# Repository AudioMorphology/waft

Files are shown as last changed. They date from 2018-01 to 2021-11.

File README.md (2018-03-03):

# waft
Eurorack Gesture Controller

## Overview

Waft is a LIDAR-based gesture controller in Eurorack format.

It is based around the VL6180x Time Of Flight controller, which measures distances using a low-power Infra-red LASER emitter but, unlike most IR distance measuring devices, which estimate distance based on reflected signals, the VL6180x measures the actual round-trip (Time Of Flight) delay. So, maybe 'gesture' perhaps overstates it slightly - it doesn't recognise gestures such as swipe up, swipe down etc., though it _**does**_ measure distance with mm accuracy over a distance of 20cm or thereabouts.... 

The VL6180X is the latest product based on ST Microelectronics'patented FlightSense™ technology. It uses a SPAD (Single Photon Avalanche Diode) array coupled with a VCSEL (Vertical Cavity Surface-Emitting Laser). The VL6180x also incorporates an Ambient Light Sensor, though we're not making use of that here.

Waft utilises the widely-available Arduino Nano V3 board as its processing core, and an mcp4728 12-Bit I2C quad-channel DAC for the CV Outputs.

Waft generates two CV and two Gate outputs:

* CV1 - 0-8v Range, not quantised
* CV2 - 0-2v Range, quantised to a series of selectable scales
* Gate 1 - On if any object detected
* gate 2 - On triggered by movement only

In addition, a CV Input can be mixed with a variable amount of CV1, thus the Waft controller can be used to modulate a CV input.

The hardware design (Schematics & Gerbers) are released under the Open Source Hardware Association (UID UK000005), and the Software is available under a Creative Commons / MIT license.

All documentation is held in the Wiki

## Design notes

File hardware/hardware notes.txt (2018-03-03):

Miniature 10-Way BCD Switches are available from various places on the web, or RS-Components, part #616-0653

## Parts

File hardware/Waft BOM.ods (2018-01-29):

Waft gesture Controller – Bill of Materials |  |  |  |  | 652-CR0805FX-3301ELF (https://www.mouser.co.uk/ProductDetail/Bourns/CR0805-FX-3301ELF)
Resistors | Value | Size | Mouser Part # | Manufacturer part number
R1 | 3k3 | 0805 | 71-RCS08053K30FKEA (https://www.mouser.co.uk/ProductDetail/Vishay/RCS08053K30FKEA) | CR0805-FX-3301ELF
R2 | 2k2 |  | 652-CR0805FX-2211ELF (https://www.mouser.co.uk/ProductDetail/Bourns/CR0805-FX-2211ELF) | CR0805-FX-2211ELF (https://www.mouser.co.uk/ProductDetail/Bourns/CR0805-FX-2211ELF)
R3 | 100k |  | 652-CR0805-FX1003GLF (https://www.mouser.co.uk/ProductDetail/Bourns/CR0805-FX-1003GLF) | CR0805-FX-1003GLF (https://www.mouser.co.uk/ProductDetail/Bourns/CR0805-FX-1003GLF)
R4 | 100k
R5 | 100k
R6 | 100k
R7 | 100k
R8 |  | There is no R8!!
R9 | 100k
R10 | 100k
R11 | 100k
R12 | 100k
R13 | 100k
R14 | 100k
R15 | 1k |  | 603-RC0805FR-071KL (https://www.mouser.co.uk/ProductDetail/Yageo/RC0805FR-071KL) | RC0805FR-071KL (https://www.mouser.co.uk/ProductDetail/Yageo/RC0805FR-071KL)
R16 | 1k
R17 | 330R |  | 71-CRCW0805-330-E3 (https://www.mouser.co.uk/ProductDetail/Vishay/CRCW0805330RFKEA) | CRCW0805330RFKEA (https://www.mouser.co.uk/ProductDetail/Vishay/CRCW0805330RFKEA)
R18 | 330R
Capacitors
C1 | 10uF | 2mm lead spacing 5mm x 11mm case | 594-MAL203858109E3 (https://www.mouser.co.uk/ProductDetail/Vishay-BC-Components/MAL203858109E3) | MAL203858109E3 (https://www.mouser.co.uk/ProductDetail/Vishay-BC-Components/MAL203858109E3)
C2 | 10uF | `
C3 | 100nF | 0805
C4 | 10n | 0805
C5 | 10uF Tant | 5mm Through hole | 581-TAP106K016CRS (https://www.mouser.co.uk/ProductDetail/AVX/TAP106K016CRS?qs=sGAEpiMZZMtZ1n0r9vR22eiMRBIfO5DbDY56e4DkAFs%3D) | TAP106K016CRS (https://www.mouser.co.uk/ProductDetail/AVX/TAP106K016CRS?qs=sGAEpiMZZMtZ1n0r9vR22eiMRBIfO5DbDY56e4DkAFs%3D)
C6 | 10n | 0805
C7 | 10n | 0805
C8 | 10n | 0805
C9 | 10n | 0805
C10 | 10n | 0805
C11 | 47pF | 0805
C12 | 47pF | 0805
C13 | 47pF | 0805
C14 | 47pF | 0805
C15 | 47pF | 0805
Variable Resistors
RV1 | 100k Linear Alps | Vertical Alpha 9mm T18 Shaft | Buy from Thonk
Knob | T18 Shaft Micro knobs | or T18 Shaft Davies Clones | Buy from Thonk
Diodes
D1 | 1N5817 | DO-41 | 621-1N5817 (https://www.mouser.co.uk/ProductDetail/Diodes-Incorporated/1N5817-T) | 1N5817-T (https://www.mouser.co.uk/ProductDetail/Diodes-Incorporated/1N5817-T)
D2 | 1N5817 | DO-41
D3 | 3mm Green LED |  | 696-SSF-LX3P74GD (https://www.mouser.co.uk/ProductDetail/Lumex/SSF-LX3P74GD?qs=sGAEpiMZZMtilyJihmhKq8Uk9pte688VLFPePNLzcpE%3D) | SSF-LX3P74GD (https://www.mouser.co.uk/ProductDetail/Lumex/SSF-LX3P74GD?qs=sGAEpiMZZMtilyJihmhKq8Uk9pte688VLFPePNLzcpE%3D)
D4 | 3mm Green LED
D5 | 1N4148 | SOD323 | 833-1N4148WX-TP | 1N4148WX-TP
D6 | 1N4148 | SOD323
ICs
U1 | MCP4728 | MSOP-10 | 579-MCP4728-E/UN (https://www.mouser.co.uk/ProductDetail/Microchip-Technology/MCP4728-E-UN) | MCP4728-E/UN (https://www.mouser.co.uk/ProductDetail/Microchip-Technology/MCP4728-E-UN)
U2 | TL071 | SOIC-8 | 595-TL071CDR (https://www.mouser.co.uk/ProductDetail/Texas-Instruments/TL071CDR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) | TL071CDR (https://www.mouser.co.uk/ProductDetail/Texas-Instruments/TL071CDR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)
U3 | TL074 | SOIC-14 | 595-TL074CDR (https://www.mouser.co.uk/ProductDetail/Texas-Instruments/TL074CDR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) | TL074CDR (https://www.mouser.co.uk/ProductDetail/Texas-Instruments/TL074CDR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)
CPU1 | Arduino nano V3 SBC |  | eBay
Other
SW1 | 10-Position binary-coded switch |  | eBay
J1 | 2-Pin Jumper 2.54mm spacing
J2 | 1-Pin
J3 | Thonkiconn Socket |  | Buy from Thonk
J4 | 2x5-Pin shrouded modular power connector |  | eBay or Alibaba
J5 | Thonkiconn Socket |  | Buy from Thonk
J6 | Thonkiconn Socket |  | Buy from Thonk
J7 | Thonkiconn Socket |  | Buy from Thonk
J8 | Thonkiconn Socket |  | Buy from Thonk
J9 | 10-Pin SIL Female header socket 2.54mm spacing |  | eBay
J10 | 10-Pin SIL Female header socket 2.54mm spacing |  | eBay
J11 | 10-Pin SIL Male header pins 2.54 spacing |  | eBay
J12 | 10-Pin SIL Male header pins 2.54 spacing |  | eBay
Arduino Socket | 2x15-Way Female Sil Socket strip |  | eBay

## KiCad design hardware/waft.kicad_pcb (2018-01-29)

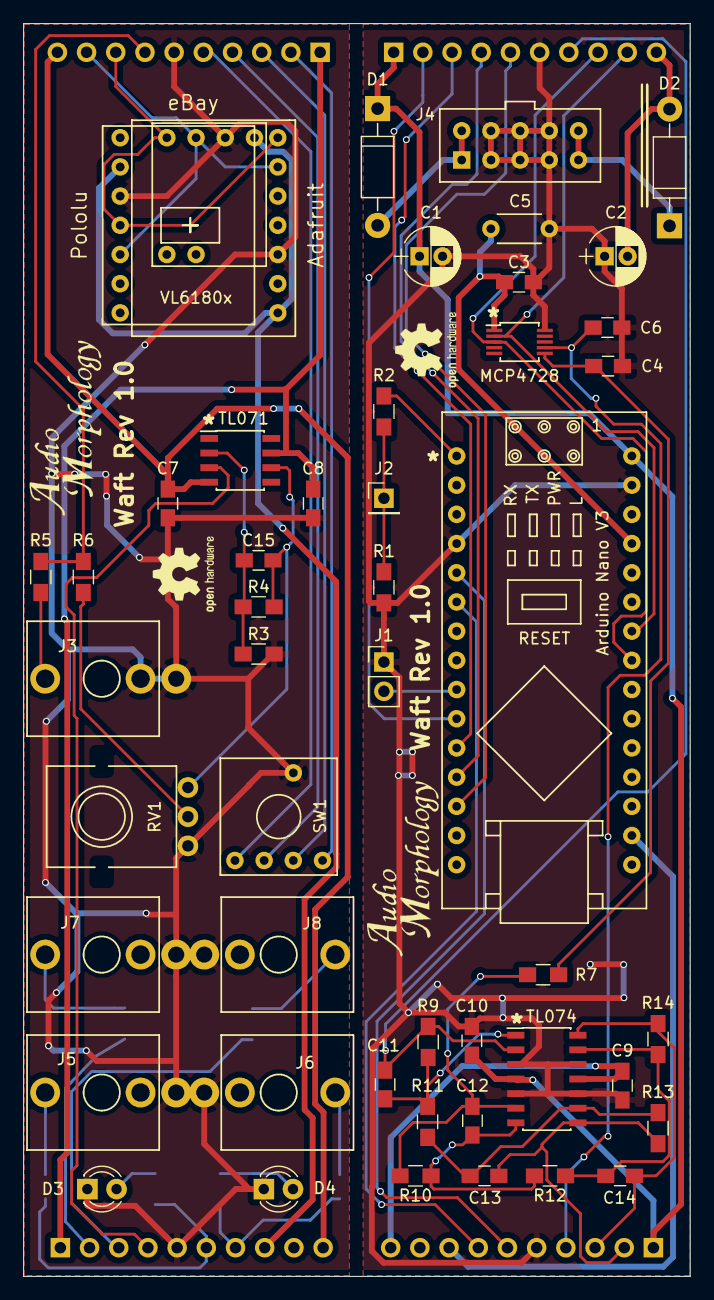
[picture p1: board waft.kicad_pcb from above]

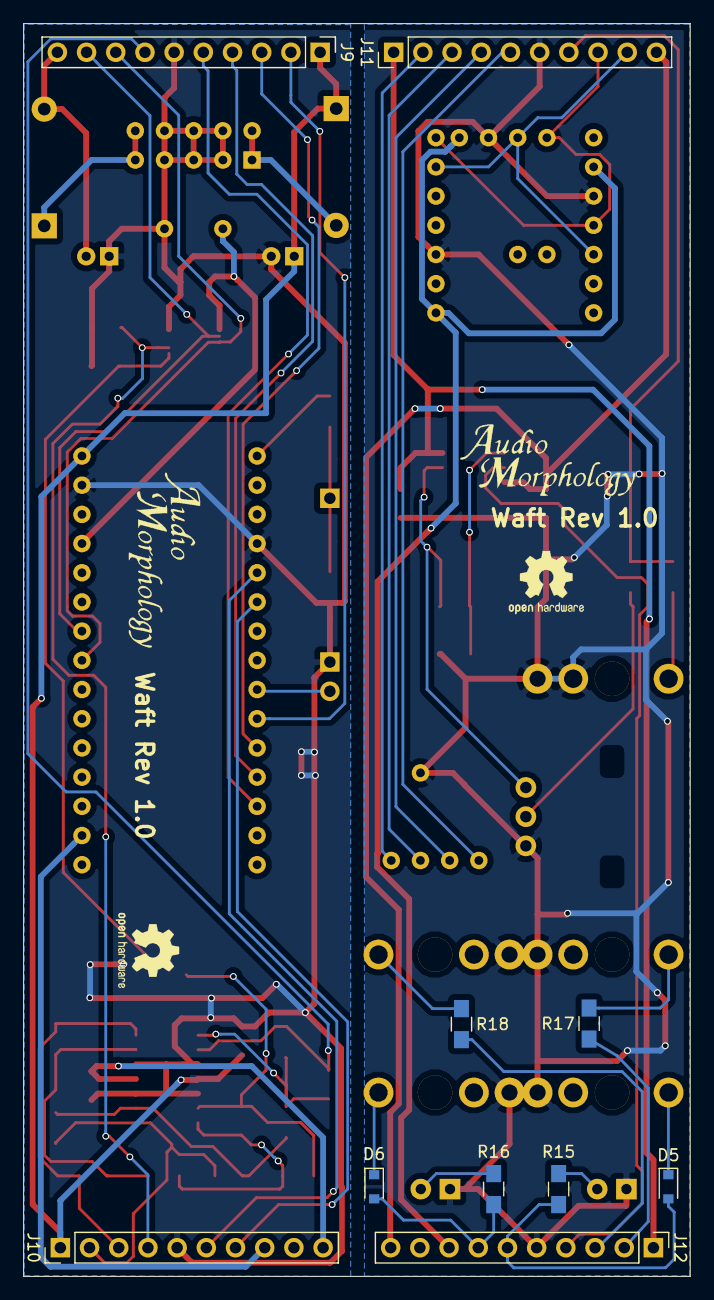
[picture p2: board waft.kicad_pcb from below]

Board: 2 copper layers, 58.0 x 109.0 mm, 57 parts (10 on the bottom side), 50 nets.

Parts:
Arduino Nano V3: Arduino_Nano_V3
C1, C2: 10uF; CP_Radial_D5.0mm_P2.00mm
C3: 100n; C_0805_HandSoldering
C4, C6, C7, C8, C9, C10: 10n; C_0805_HandSoldering
C5: 10uF Tant; tantalum_capacitor
C11, C12, C13, C14, C15: 47pF; C_0805_HandSoldering
D1, D2: 1N5817; D_DO-41_SOD81_P10.16mm_Horizontal
D3, D4: LED; LED_D3.0mm
D5, D6: 1N4148; D_0805
J1: CONN_01X02; Pin_Header_Straight_1x02_Pitch2.54mm
J2: CONN_01X01; Pin_Header_Straight_1x01_Pitch2.54mm
J3, J5, J6, J7, J8: Thonkiconn
J4: Conn_02x05_Odd_Even; IDC-2x5
J9, J10: Conn_01x10_Female; Pin_Header_Straight_1x10_Pitch2.54mm
J11, J12: Conn_01x10_Male; Pin_Header_Straight_1x10_Pitch2.54mm
MCP4728: MCP4728; MSOP-10_3x3mm_Pitch0.5mm
R1: 3k3; R_0805_HandSoldering
R2: 2k2; R_0805_HandSoldering
R3, R4, R5, R6, R7, R9, R10, R11, R12, R13, R14: 100k; R_0805_HandSoldering
R15, R16: 1k; R_0805_HandSoldering
R17, R18: 330R; R_0805_HandSoldering
RV1: B100K; Alpha_9mm_Vertical
SW1: Coded_Switch; 10_Way_Coded_Switch
TL071: TL071; SOIC-8_3.9x4.9mm_Pitch1.27mm
TL074: TL074; SOIC-14_3.9x8.7mm_Pitch1.27mm
VL6180x: VL6180x_Composite

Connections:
+3V3: Arduino Nano V3.17, J10.8, J12.8, VL6180x.2, VL6180x.11, VL6180x.14
+5V: Arduino Nano V3.27, C3.1, C5.1, MCP4728.1
+12V: Arduino Nano V3.30, C1.1, C8.2, C10.2, D1.1, J9.1, J10.1, J11.1, J12.1, TL071.7, TL074.4
-12V: C2.2, C7.1, C9.1, D2.2, J9.10, J10.10, J11.10, J12.10, TL071.4, TL074.11
CV1a: C13.1, J10.2, R13.1, TL074.8
CV1b: J12.2, R17.2
CV2a: C14.1, J10.3, R14.1, TL074.14
CV2b: J12.3, R18.2
D0b: J11.2, SW1.2
D1a: Arduino Nano V3.11, J9.3
D1b: J11.3, SW1.3
D2a: Arduino Nano V3.12, J9.4
D2b: J11.4, SW1.4
D3a: Arduino Nano V3.13, J9.5
D3b: J11.5, SW1.5
DAC_A: C4.1, MCP4728.6, R7.2
DAC_Ba: C6.1, J10.4, MCP4728.7
DAC_Bb: J12.4, TL071.3
DIR: Arduino Nano V3.9, J1.2
DOa: Arduino Nano V3.10, J9.2
GATE_1a: Arduino Nano V3.5, J10.6
GATE_1b: D5.2, J12.6, R15.2
GATE_2a: Arduino Nano V3.6, J10.7
GATE_2b: D6.2, J12.7, R16.2
GND: Arduino Nano V3.4, Arduino Nano V3.29, C1.2, C2.1, C3.2, C4.2, C5.2, C6.2, C7.2, C8.1, C9.2, C10.1, D3.1, D4.1, J1.1, J3.1, J3.2, J4.3, J4.4, J4.5, J4.6, J4.7, J4.8, J5.1, J6.1, J7.1, J8.1, J9.6, J10.5, J11.6, J12.5, MCP4728.10, R1.2, R3.2, RV1.3, SW1.1, TL074.3, TL074.5, TL074.10, TL074.12, VL6180x.3, VL6180x.10, VL6180x.16
MIXa: C11.2, J9.7, R9.2, TL074.2
MIXb: J11.7, R5.1, R6.1
unnamed: C11.1, R9.1, R11.2, TL074.1
unnamed: C12.1, R10.1, R12.2, TL074.7
unnamed: C12.2, R7.1, R10.2, TL074.6
unnamed: C13.2, R11.1, R13.2, TL074.9
unnamed: C14.2, R12.1, R14.2, TL074.13
unnamed: C15.1, R4.1, RV1.1, TL071.6
unnamed: C15.2, R3.1, R4.2, TL071.2
unnamed: Arduino Nano V3.1, R2.1
unnamed: D1.2, J4.1, J4.2
unnamed: D2.1, J4.9, J4.10
unnamed: D3.2, R15.1
unnamed: D4.2, R16.1
unnamed: D5.1, J5.3
unnamed: D6.1, J6.3
unnamed: J2.1, R1.1, R2.2
unnamed: J3.3, R5.2
unnamed: J7.3, R17.1
unnamed: J8.3, R18.1
unnamed: R6.2, RV1.2
SCLa: Arduino Nano V3.24, J9.9, MCP4728.2
SCLb: J11.9, VL6180x.5, VL6180x.9, VL6180x.19
SDAa: Arduino Nano V3.23, J9.8, MCP4728.3
SDAb: J11.8, VL6180x.4, VL6180x.8, VL6180x.20

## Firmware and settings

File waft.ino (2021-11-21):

// Copyright 2016 Richard R. Goodwin / Audio Morphology.
//
// Author: Richard R. Goodwin (richard.goodwin@morphology.co.uk)
//
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
// See http://creativecommons.org/licenses/MIT/ for more information.
//
// 19-Feb-2018
#line 1 "waft.ino"

#include "Arduino.h"
void setup();
void loop();
#line 4
void printStatus();
int quantize_val(int, int, int);
void log_msg(const char*, ...);

#include <Wire.h>
#include "mcp4728.h"
#include "Adafruit_VL6180X.h"
#define SMOOTHING 4
#define MOVEMENT_HYSTERESIS 100

Adafruit_VL6180X vl = Adafruit_VL6180X();
mcp4728 dac = mcp4728(0); // instantiate mcp4728 object, Device ID = 0
uint16_t buff[50];
uint8_t write_ptr = 0;
int p_gate1 = 2;     // Gate 1 is triggered when ANY range signal is detected
int p_gate2 = 3;     // gate 2 is triggered by MOVEMENT
int p_invert = 6;     // Internal Pullup, pulled low by external jumper
int p_intonation = 5; // Internal pullup, pulled low by external jumper (sets intonation to Just or Equal)
int p_debug = 4;      // Pin indicates whether to transmit debug messages
int p_D0 = 7;
int p_D1 = 8;
int p_D2 = 9;
int p_D3 = 10;
int quantize = 0;
int debug = 1;
float prev_av = 0;

void setup()
{
  pinMode(p_gate1, OUTPUT);
  pinMode(p_gate2, OUTPUT);
  pinMode(p_invert, INPUT_PULLUP);
  pinMode(p_intonation, INPUT_PULLUP);
  pinMode(p_debug, INPUT_PULLUP);
  pinMode(p_D0, INPUT_PULLUP);
  pinMode(p_D1, INPUT_PULLUP);
  pinMode(p_D2, INPUT_PULLUP);
  pinMode(p_D3, INPUT_PULLUP);
  Serial.begin(9600);  // initialize serial interface for print()
  //NOTE: Always print copyright to the Serial port - don't use the log_msg() wrapper
  Serial.println("Waft by Audio Morphology");
  Serial.println("Copyright 2016 Richard R. Goodwin / Audio Morphology.");
  Serial.println(" ");
  dac.begin();  // initialize i2c interface
  dac.vdd(5000); // set VDD(mV) of MCP4728 for correct conversion between LSB and Vout
  if (! vl.begin()) {
    log_msg("Failed to find VL6180X Sensor\n\r");
    while (1);
  }
  log_msg("VL6180x Sensor found!\n\r");
  dac.setVref(1,1,1,1); // set to use internal voltage reference (2.048V)
  dac.setGain(0, 0); // set the gain of internal voltage reference ( 2.048V x 2 = 4.096V )
  dac.setGain(1, 1); // set the gain of internal voltage reference ( 2.048V x 2 = 4.096V )
  printStatus(); // Print all internal value and setting of input register and EEPROM. 
}


void loop()
{
  float av_val;
  float no_quant;
  int invert = digitalRead(p_invert);
  int intonation = digitalRead(p_intonation);
  debug = digitalRead(p_debug);
  int D0 = digitalRead(p_D0);
  int D1 = digitalRead(p_D1);
  int D2 = digitalRead(p_D2);
  int D3 = digitalRead(p_D3);
  quantize = 0;
  if(D0 == 0) quantize += 1;
  if(D1 == 0) quantize += 2;
  if(D2 == 0) quantize += 4;
  if(D3 == 0) quantize += 8;
  if((quantize < 0) || (quantize > 9)) quantize = 0;
  uint8_t range = vl.readRange();
  if(range != 255) log_msg("Range: %d\n\r",range);
  uint8_t status = vl.readRangeStatus();
  if (status == VL6180X_ERROR_NONE) {
    // Gate On
    digitalWrite(p_gate1, HIGH);
    // Range values are likely to be approx 15 - 190
    // but treat the useable range as 15 - 175
    // so scale these to a 0 - 4000 value
    if(range > 15){range -= 15;} else {range = 0;}
    if(range > 160){range = 160;}
    //log_msg("Range: %d\n\r",range);
    if(invert == LOW){
      buff[write_ptr] = (160-range)*25;
    }
    else {
      buff[write_ptr] = (range)*25;
    }
    if(write_ptr++ >= SMOOTHING) { 
      write_ptr = 0;
    }
    // Average this with previous
    av_val = 0;
    int i = 0;
    for(i = 0; i < SMOOTHING; i++) {
       av_val += buff[i];
    }
    av_val = av_val/SMOOTHING;
    no_quant = av_val;
    
    // Quantise appropriately
    av_val = quantize_val(av_val, quantize, intonation);

    // DAC Channel 1 = 2 Octave range, quantised where necessary
    // DAC Channel 2 = 4v Range, never quantised
    dac.analogWrite(av_val,no_quant,av_val,av_val);
    // Gate2 On if the value has changed
    if((av_val <= prev_av - MOVEMENT_HYSTERESIS) || (av_val >= prev_av + MOVEMENT_HYSTERESIS)) {
      prev_av = av_val;
      digitalWrite(p_gate2, HIGH); 
    }
    else {
      digitalWrite(p_gate2, LOW); 
    }
  }
  else {
     // basically treat all returned values other 
     // than VL6180X_ERROR_NONE as no signal, so gate off
     digitalWrite(p_gate1, LOW); 
     digitalWrite(p_gate2, LOW);
  }
//#define VL6180X_ERROR_NONE         0   ///< Success!
//#define VL6180X_ERROR_SYSERR_1     1   ///< System error
//#define VL6180X_ERROR_SYSERR_5     5   ///< Sysem error
//#define VL6180X_ERROR_ECEFAIL      6   ///< Early convergence estimate fail  
//#define VL6180X_ERROR_NOCONVERGE   7   ///< No target detected
//#define VL6180X_ERROR_RANGEIGNORE  8   ///< Ignore threshold check failed
//#define VL6180X_ERROR_SNR          11  ///< Ambient conditions too high
//#define VL6180X_ERROR_RAWUFLOW     12  ///< Raw range algo underflow
//#define VL6180X_ERROR_RAWOFLOW     13  ///< Raw range algo overflow
//#define VL6180X_ERROR_RANGEUFLOW   14  ///< Raw range algo underflow
//#define VL6180X_ERROR_RANGEOFLOW   15  ///< Raw range algo overflow
}

void printStatus()
{
  log_msg("NAME     Vref  Gain  PowerDown  Value\n");
  for (int channel=0; channel <= 3; channel++)
  {  
    log_msg("DAC%d       %d     %d       %d       %d\n\r",channel,dac.getVref(channel),dac.getGain(channel),dac.getPowerDown(channel),dac.getValue(channel));
    log_msg("EEPROM%d    %d     %d       %d       %d\n\r",channel,dac.getVrefEp(channel),dac.getGainEp(channel),dac.getPowerDownEp(channel),dac.getValueEp(channel));
  }
  log_msg(" \n\r");
}

// Wrapper for the Serial.print function that
// enables us to turn off debug messages. This
// is simply because the overhead of writing
// debug messages to the serial port slows down
// the main program loop
void log_msg(const char* format, ...)
{
   char buf[128];
  if (debug == 1){
  va_list args;
  va_start(args, format);
  vsnprintf(buf, sizeof(buf), format, args);
  Serial.print(buf);
  va_end(args);
  }
}

// Qantizes the passed input value
// to different scales depending on
// the chosen scale, and intonaztion
// (Equal temperament or Just Intonation)
int quantize_val(int in_val, int scale, int intonation){
  int retval;
  //log_msg("In val: %d\n\r",in_val);
  switch(intonation){
    // Just Intonation
    case 0:
      //Serial.println("Just Intonation");
      switch(scale){
        case 0:
            retval = in_val;  // scale == 0 don't quantize
          break;
        case 1:
          // Chromatic (Just Intonation)
          switch(in_val){
            case 0 ... 159:
                retval = 0;
                break;
            case 160 ... 319:
                retval = 150;
                break;
            case 320 ... 479:
                retval = 340;
                break;
            case 480 ... 639:
                retval = 490;
                break;
            case 640 ... 799:
                retval = 680;
                break;
            case 800 ... 959:
                retval = 830;
                break;
            case 960 ... 1119:
                retval = 980;
                break;
            case 1120 ... 1279:
                retval = 1170;
                break;
            case 1280 ... 1439:
                retval = 1320;
                break;
            case 1440 ... 1599:
                retval = 1510;
                break;
            case 1600 ... 1759:
                retval = 1660;
                break;
            case 1760 ... 1919:
                retval = 1850;
                break;
            case 1920 ... 2079:
                retval = 2000;
                break;
            case 2080 ... 2239:
                retval = 2150;
                break;
            case 2240 ... 2399:
                retval = 2340;
                break;
            case 2400 ... 2559:
                retval = 2490;
                break;
            case 2560 ... 2719:
                retval = 2680;
                break;
            case 2720 ... 2879:
                retval = 2830;
                break;
            case 2880 ... 3039:
                retval = 2980;
                break;
            case 3040 ... 3199:
                retval = 3170;
                break;
            case 3200 ... 3359:
                retval = 3320;
                break;
            case 3360 ... 3519:
                retval = 3510;
                break;
            case 3520 ... 3679:
                retval = 3660;
                break;
            case 3680 ... 3839:
                retval = 3850;
                break;
            case 3840 ... 4000:
                retval = 4000;
                break;
          }
          break;
        case 2:
          // Major (Just Intonation)
          switch(in_val){
            case 0 ... 266:
                retval = 0;
                break;
            case 267 ... 533:
                retval = 340;
                break;
            case 534 ... 800:
                retval = 680;
                break;
            case 801 ... 1067:
                retval = 830;
                break;
            case 1068 ... 1334:
                retval = 1170;
                break;
            case 1335 ... 1601:
                retval = 1510;
                break;
            case 1602 ... 1868:
                retval = 1850;
                break;
            case 1869 ... 2135:
                retval = 2000;
                break;
            case 2136 ... 2402:
                retval = 2340;
                break;
            case 2403 ... 2669:
                retval = 2680;
                break;
            case 2670 ... 2936:
                retval = 2830;
                break;
            case 2937 ... 3203:
                retval = 3170;
                break;
            case 3204 ... 3470:
                retval = 3510;
                break;
            case 3471 ... 3737:
                retval = 3850;
                break;
            case 3738 ... 4000:
                retval = 4000;
                break;
          }
          break;
        case 3:
          // Major Pentatonic (Just Intonation)
          switch(in_val){
            case 0 ... 363:
                retval = 0;
                break;
            case 364 ... 727:
                retval = 340;
                break;
            case 728 ... 1091:
                retval = 680;
                break;
            case 1092 ... 1455:
                retval = 1170;
                break;
            case 1456 ... 1819:
                retval = 1510;
                break;
            case 1820 ... 2183:
                retval = 2000;
                break;
            case 2184 ... 2547:
                retval = 2340;
                break;
            case 2548 ... 2911:
                retval = 2680;
                break;
            case 2912 ... 3275:
                retval = 3170;
                break;
            case 3276 ... 3639:
                retval = 3510;
                break;
            case 3640 ... 4000:
                retval = 4000;
                break;
          }
        
          break;
        case 4:
          // Minor Pentatonic (Just Intonation)
          switch(in_val){
            case 0 ... 363:
                retval = 0;
                break;
            case 364 ... 727:
                retval = 370;
                break;
            case 728 ... 1091:
                retval = 667;
                break;
            case 1092 ... 1455:
                retval = 1000;
                break;
            case 1456 ... 1819:
                retval = 1555;
                break;
            case 1820 ... 2183:
                retval = 2000;
                break;
            case 2184 ... 2547:
                retval = 2370;
                break;
            case 2548 ... 2911:
                retval = 2667;
                break;
            case 2912 ... 3275:
                retval = 3000;
                break;
            case 3276 ... 3639:
                retval = 3555;
                break;
            case 3640 ... 4000:
                retval = 4000;
                break;
          }
        
          break;
        case 5:
          // Harmonic Minor (Just Intonation)
          switch(in_val){
            case 0 ... 266:
                retval = 0;
                break;
            case 267 ... 533:
                retval = 340;
                break;
            case 534 ... 800:
                retval = 490;
                break;
            case 801 ... 1067:
                retval = 830;
                break;
            case 1068 ... 1334:
                retval = 1170;
                break;
            case 1335 ... 1601:
                retval = 1320;
                break;
            case 1602 ... 1868:
                retval = 1850;
                break;
            case 1869 ... 2135:
                retval = 2000;
                break;
            case 2136 ... 2402:
                retval = 2340;
                break;
            case 2403 ... 2669:
                retval = 2490;
                break;
            case 2670 ... 2936:
                retval = 2830;
                break;
            case 2937 ... 3203:
                retval = 3170;
                break;
            case 3204 ... 3470:
                retval = 3320;
                break;
            case 3471 ... 3737:
                retval = 3850;
                break;
            case 3738 ... 4000:
                retval = 4000;
                break;
          }
          break;
        case 6:
          // Dorian (Just Intonation)
          switch(in_val){
            case 0 ... 266:
                retval = 0;
                break;
            case 267 ... 533:
                retval = 340;
                break;
            case 534 ... 800:
                retval = 490;
                break;
            case 801 ... 1067:
                retval = 830;
                break;
            case 1068 ... 1334:
                retval = 1170;
                break;
            case 1335 ... 1601:
                retval = 1510;
                break;
            case 1602 ... 1868:
                retval = 1660;
                break;
            case 1869 ... 2135:
                retval = 2000;
                break;
            case 2136 ... 2402:
                retval = 2340;
                break;
            case 2403 ... 2669:
                retval = 2490;
                break;
            case 2670 ... 2936:
                retval = 2830;
                break;
            case 2937 ... 3203:
                retval = 3170;
                break;
            case 3204 ... 3470:
                retval = 3510;
                break;
            case 3471 ... 3737:
                retval = 3660;
                break;
            case 3738 ... 4000:
                retval = 4000;
                break;
          }
    
          break;
        case 7:
          // Phrygian (Just Intonation)
          switch(in_val){
            case 0 ... 266:
                retval = 0;
                break;
            case 267 ... 533:
                retval = 150;
                break;
            case 534 ... 800:
                retval = 490;
                break;
            case 801 ... 1067:
                retval = 830;
                break;
            case 1068 ... 1334:
                retval = 1170;
                break;
            case 1335 ... 1601:
                retval = 1320;
                break;
            case 1602 ... 1868:
                retval = 1660;
                break;
            case 1869 ... 2135:
                retval = 2000;
                break;
            case 2136 ... 2402:
                retval = 2150;
                break;
            case 2403 ... 2669:
                retval = 2490;
                break;
            case 2670 ... 2936:
                retval = 2830;
                break;
            case 2937 ... 3203:
                retval = 3170;
                break;
            case 3204 ... 3470:
                retval = 3320;
                break;
            case 3471 ... 3737:
                retval = 3660;
                break;
            case 3738 ... 4000:
                retval = 4000;
                break;
          }
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

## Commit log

2017-04-07 Rev 1.0 Schematic upload
    [waft.kicad_pcb, waft.sch]
2017-04-07 KiCad Library upload
2017-04-11 added support for rotary BCD switch for quantisation selection
2018-01-15 Updated KiCad project-specific footprint & 3D Model
2018-01-15 Schematic changes.
    Couple of changes to the schematic, & started laying out the PCB.
    [waft.kicad_pcb, waft.sch]
2018-01-16 Started board layout
    [waft.kicad_pcb, waft.sch]
2018-01-16 Arduino 3D Model
2018-01-16 Top and bottom track routing
    [waft.kicad_pcb]
2018-01-19 Started Front panel design
    [waft.kicad_pcb, waft_frontpanel.kicad_pcb]
2018-01-21 Silk screen graphics
    [waft.kicad_pcb, waft.sch]
2018-01-21 Added Gerber files for Waft PCB
    [waft-B.Cu.gbr, waft-B.SilkS.gbr, waft-Eco1.User.gbr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]
2018-01-22 final cosmetic adjustments to Rev 1.0 Layout
    [waft.kicad_pcb]
2018-01-22 Rev 1 Gerbers as sent for fabrication
    [waft-B.Cu.gbr, waft-B.SilkS.gbr, waft-Eco1.User.gbr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]
2018-01-22 Forgot the solder mask layers!
    [waft-B.Cu.gbr, waft-B.Mask.gbr, waft-B.SilkS.gbr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]
2018-01-22 Initial Bill of Materials
    [Waft BOM.ods]
2018-01-29 Rev 1.0 Sent for fabrication
    [Waft BOM.ods, waft.kicad_pcb, waft_frontpanel.kicad_pcb]
2018-01-29 Rev 1.0 Gerbers as sent for fabrication
2018-01-30 Update KiCad library
